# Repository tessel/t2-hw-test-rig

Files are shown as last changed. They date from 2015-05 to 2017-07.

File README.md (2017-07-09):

# t2-hw-test-rig



KiCAD design files for test rigs for Technical Machine's Tessel 2

To download [TM's KiCAD library](https://github.com/technicalmachine/tm-kicad-library), containing all the schematic symbols and footprints, run this command:

```
git submodule update --init
```

## Notes

* We use the daily builds of KiCAD (for [Ubuntu](https://code.launchpad.net/~js-reynaud/+archive/ubuntu/ppa-kicad and [OS X](http://www.kicad-pcb.org/display/KICAD/Installing+KiCad#InstallingKiCad-MacOSX) ) and you should too!
* As a general rule, do not assume that schematic, layout, and manufacturig exports were kept abreast on each commit. Do a fresh export (or use tagged releases) if you intend to actually send off gerbers.

### Troubleshooting

**No components rendered in 3D viewer (OS X):** You may need to change the environment variable for the 3D model path. Run this command and reset KiCad; this fix will work for the duration of your logged in session on the computer:

```
launchctl setenv KISYS3DMOD "/Library/Application Support/kicad/packages3d"
```

## Mechanical Model

Our [physical CAD model](https://cad.onshape.com/documents/50a5c011c1d44d7ca5c90fbf) is available on [OnShape](http://onshape.com), a cloud-based 3D CAD system that is free for public projects. It supports export in a variety of formats to other 3D CAD tools.

## License

CC-BY-SA and/or Solderpad at your option except where otherwise noted.

See `license.txt`.

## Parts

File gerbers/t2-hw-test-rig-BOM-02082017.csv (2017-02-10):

Title | Tessel 2 Test Rig
Revision
Date | Thu 30 Apr 2015
Generated | Monday | May 30 | 2016 'PMt' 12:41:19 PM
Company | Technical Machine | Inc.
Comment 1 | Copyright 2015
Comment 2 | CC-BY-SA and/or Solderpad at your option
Comment 3
Comment 4
Total Parts | 198
Total Unique Parts | 49
Ref | Qty | Value | Footprint
C104 C102 C103 C105 C310 C305 C307 C303 C302 C313 C311 C314 C401 C403 C409 C410 C404 C414 C505 C502 C508 C504 | 22 | 100nF | SMD-0402
C101 C308 C309 C312 | 4 | 10uF | SMD-0402
C201 C207 C202 C405 C411 C412 C406 C415 C503 C506 C509 | 11 | 100pF | SMD-0402
C304 C301 | 2 | 10pF | SMD-0402
C306 | 1 | 1uF | SMD-0402
C501 | 1 | 100nF DNP | SMD-0402
D203 D201 | 2 | PRTR5V0U2X | SMD
D304 | 1 | RED LEDs | LED-0603
D302 | 1 | YELLOW LEDs | LED-0603
D303 | 1 | GREENLEDs | LED-0603
D301 | 1 | BLUELEDs | LED-0603
H601 H602 H603 H604 H605 H606 H607 H608 H609 H610 H611 H612 | 12 | M2.5 | MountingHole_2-5mm
J102 | 1 | BARREL_JACK
J101 J103 J202 | 3 | CONN_01X02 | Pin_Header_Straight_1x02
J201 J203 | 2 | MICROUSB-TH
J204 | 1 | USB_A_TH
J301 | 1 | CONN_02x05 | 0.05 CONN_02x05_0.05in
JP101 JP201 | 2 | JUMPER
L301 L401 L502 | 3 | 10uHtm-kicad-lib | SMD-0603-R
L501 | 1 | 10uH DNP
MP601 MP602 MP606 MP607 MP610 MP611 MP614 MP615 MP620 MP625 MP630 | 11 | Mounting Hardware - See Schematic, Mechanical Sheet
MP603 | 1 | Mounting Hardware - See Schematic, Mechanical Sheet
MP605 MP609 MP613 MP617 MP622 MP627 MP632 | 7 | Mounting Hardware - See Schematic, Mechanical Sheet
MP633 | 1 | Mounting Hardware - See Schematic, Mechanical Sheet
MP618 MP623 MP628 | 3 | Mounting Hardware - See Schematic, Mechanical Sheet
MP604 MP608 MP612 MP616 MP621 MP626 MP631 MP619 MP624 MP629 | 10 | Mounting Hardware - See Schematic, Mechanical Sheet
P102 P103 | 2 | USB A TO MicroUSB A CABLE
P104 | 1 | ETHERNET CABLE
P101 | 1 | 5VDC POWER
P105 P106 | 2 | USB THUMB DRIVE
Q101 | 1 | pMOS | SOT-23
Q403 Q401 Q402 Q404 | 4 | NTR4503NT1G | SOT-23
Q405 Q406 | 2 | CJ2302 DNP | SOT-23
R201 R202 R206 R203 | 4 | 100k | SMD-0402-R
R308 R309 R304 R301 | 4 | 1k | SMD-0402-R
R306 R307 R305 R310 R405 R401 R402 R406 R501 R502 | 10 | 10k | SMD-0402-R
R302 | 1 | 330 | SMD-0402-R
R303 | 1 | 120 | SMD-0402-R
R407 R403 R404 R408 R409 | 5 | 20m | SMD-0805-R
RN502 RN503 RN501 RN504 | 4 | ACASA100221002P100 | SMT | http://www.digikey.com/product-detail/en/vishay-beyschlag/ACASA100221002P100/ACASA-10K-10K-2CT-ND/1869887
SW301 SW302 | 2 | Switch_DPST
TP321 TP302 TP303 TP305 TP306 TP307 TP308 TP309 TP310 TP311 TP312 TP313 TP317 TP318 TP315 TP316 TP314 TP301 TP304 TP324 TP319 TP325 TP326 TP327 TP328 TP401 TP403 TP404 TP402 TP507 TP505 TP503 TP504 TP509 | 34 | 0932-0-15-20-77-14-11-0
U101 | 1 | MAX6102 | SOT-23
U102 | 1 | XC6206P332MR-G | SOT-23
U301 | 1 | ATSAMD21J18A-MUT
U302 U303 | 2 | AAT4610 | SOT-23
U403 U401 U402 U404 U405 | 5 | MAX9919FASA | SOIC-8
U502 U501 U503 | 3 | TSV324IDT | SOIC-14
X301 | 1 | FC-135 | SMT | http://www.seeedstudio.com/wiki/images/7/78/306010055.pdf
BOM made with KICAD_BOM_WIZARD (https://github.com/HashDefineElectronics/KiCad_BOM_Wizard.git)
Generated Monday | May 30 | 2016 'PMt' 12:41:19 PM

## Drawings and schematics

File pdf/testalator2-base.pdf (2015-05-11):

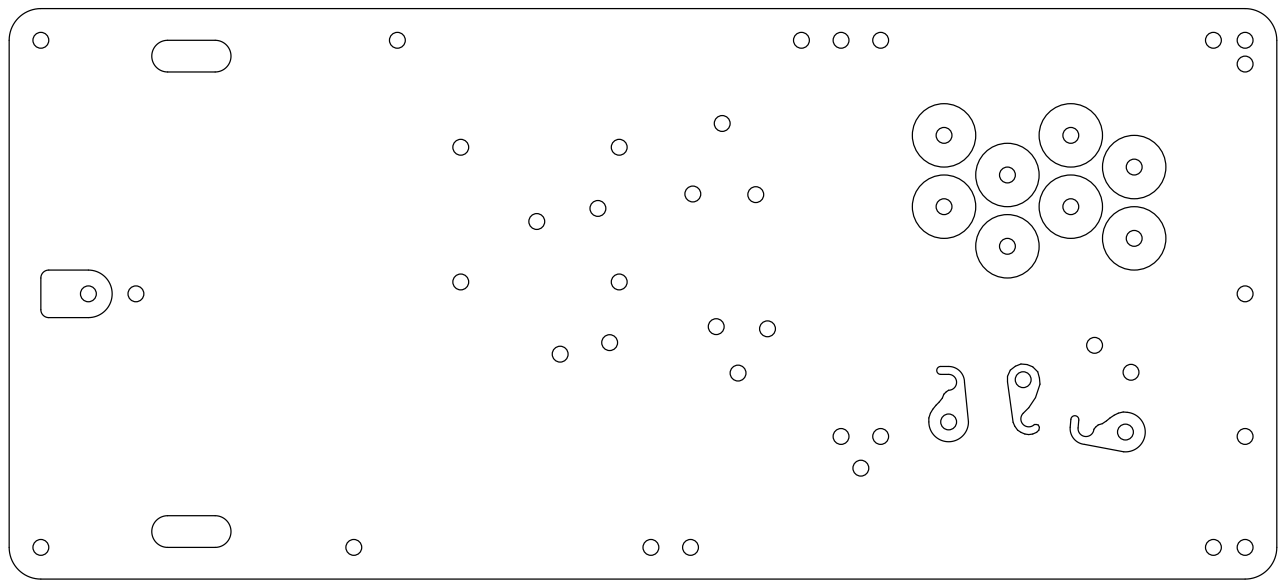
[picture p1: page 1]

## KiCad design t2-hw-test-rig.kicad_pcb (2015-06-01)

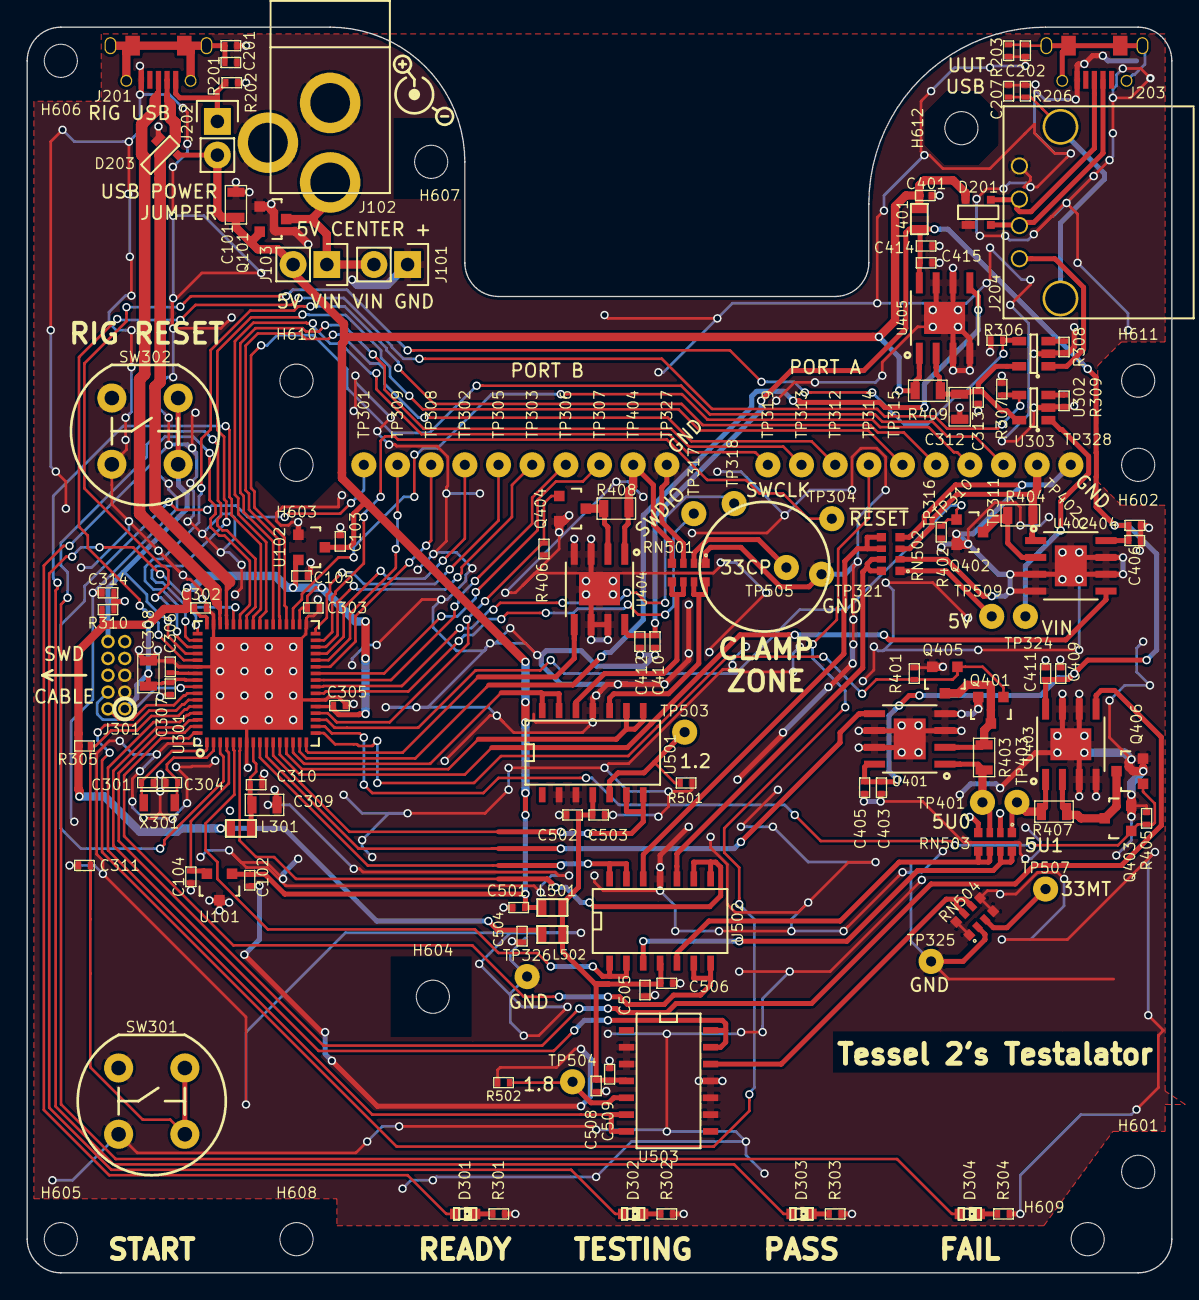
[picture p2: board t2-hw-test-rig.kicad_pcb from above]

Board: 2 copper layers, 86.4 x 94.0 mm, 157 parts (0 on the bottom side), 95 nets.

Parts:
C101, C308, C309, C312: 10uF; SMD-0805-C
C102, C103, C104, C105, C302, C303, C305, C307, C310, C311, C313, C314, C401, C403, C404, C409, C410, C414, C502, C504, C505, C508: 100nF; SMD-0402-C
C201, C202, C207, C405, C406, C411, C412, C415, C503, C506, C509: 100pF; SMD-0402-C
C301, C304: 10pF; SMD-0402-C
C306: 1uF; SMD-0402-C
C501: 100nF DNP; SMD-0402-C
D201, D203: PRTR5V0U2X,215
D301: BLUE; LED-0603
D302: YELLOW; LED-0603
D303: GREEN; LED-0603
D304: RED; LED-0603
H601, H602, H603, H604, H605, H606, H607, H608, H609, H610, H611, H612: M2.5; MountingHole_2-5mm
J101, J103, J202: CONN_01X02; Pin_Header_Straight_1x02
J102: BARREL_JACK
J201, J203: MICROUSB-TH; Seeed-USB-Micro-320010028
J204: USB_A_TH; USB-A
J301: CONN_02x05, 0.05"; CONN_02x05_0.05in
L301, L401, L502: 10uH; SMD-0603-R
L501: 10uH DNP; SMD-0603-R
Q101: pMOS; SOT-23
Q401, Q402, Q403, Q404: CJ2302; SOT-23
Q405, Q406: CJ2302 DNP; SOT-23
R201, R202, R203, R206: 100kR; SMD-0402-R
R301, R304, R308, R309: 1kR; SMD-0402-R
R302: 330R; SMD-0402-R
R303: 120R; SMD-0402-R
R305, R306, R307, R310, R401, R402, R405, R406, R501, R502: 10kR; SMD-0402-R
R403, R404, R407, R408, R409: 20mR 1%; SMD-0805-R
RN501, RN502, RN503, RN504: ACASA100221002P100; ACAS0612
SW301, SW302: Switch_DPST; SPST-TH
TP301, TP302, TP303, TP304, TP305, TP306, TP307, TP308, TP309, TP310, TP311, TP312, TP313, TP314, TP315, TP316, TP317, TP318, TP319, TP321, TP324, TP325, TP326, TP327, TP328, TP401, TP402, TP403, TP404, TP503, TP504, TP505, TP507, TP509: 0932-0-15-20-77-14-11-0
U101: MAX6102; SOT-23
U102: XC6206P332MR-G; SOT-23
U301: ATSAMD21J18A-MUT; QFN-64-1EP_9x9x0.5-8MILDRC
U302, U303: AAT4610; SOT-23-5
U401, U402, U403, U404, U405: MAX9919FASA+; SOIC-8-N-1EP
U501, U502, U503: TSV324IDT; SOIC-14_N
X301: FC-135

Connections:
5VUSB0_DIV_BUFF: U301.64, U502.6, U502.7
5VUSB1_DIV_BUFF: U301.5, U502.1, U502.2
5V_DIV_BUFF: U301.6, U502.8, U502.9
12_BUFF: U301.11, U501.6, U501.7
18_BUFF: U301.61, U503.6, U503.7
33CP_DIV_BUFF: U301.13, U501.8, U501.9
33MT_DIV_BUFF: U301.62, U503.13, U503.14
33PA_DIV_BUFF: U301.9, U502.13, U502.14
33PB_DIV_BUFF: U301.14, U501.13, U501.14
+3V3: C105.1, C302.1, C303.1, C305.1, C307.1, C308.1, C504.1, J301.1, L301.1, L502.2, R305.2, R310.2, U102.2, U301.21, U301.34, U301.48, U301.56
+5V: C101.1, C102.1, C103.1, C401.1, C501.1, D201.4, D203.4, J103.2, J202.2, L401.2, L501.2, Q101.2, R409.1, U101.1, U102.3, U405.1
/CURRENT/5VUSB0_RS-: Q401.3, Q405.3, R403.2, U401.2
/CURRENT/5VUSB1_RS-: Q403.3, Q406.3, R407.2, U403.2
/CURRENT/33PA_RS-: Q402.3, R404.2, U402.2
/CURRENT/33PB_RS-: Q404.3, R408.2, U404.2
/CURRENT/VCC_CSA: C403.1, C404.1, C405.1, C406.1, C409.1, C410.1, C411.1, C412.1, C414.1, C415.1, L401.1, U401.8, U402.8, U403.8, U404.8, U405.8
/OP AMPS/5VUSB0_DIV: RN503.5, RN503.6, U502.5
/OP AMPS/5VUSB1_DIV: RN503.7, RN503.8, U502.3
/OP AMPS/5V_DIV: RN502.7, RN502.8, U502.10
/OP AMPS/33CP_DIV: RN501.7, RN501.8, U501.10
/OP AMPS/33MT_DIV: RN504.6, RN504.7, U503.12
/OP AMPS/33PA_DIV: RN502.5, RN502.6, U502.12
/OP AMPS/33PB_DIV: RN501.5, RN501.6, U501.12
/OP AMPS/UUT_12: R501.1, TP503.~, U501.5
/OP AMPS/UUT_18: R502.1, TP504.~, U503.5
/OP AMPS/VDD_OPAMPS: C502.1, C503.1, C505.1, C506.1, C508.1, C509.1, L501.1, L502.1, U501.4, U502.4, U503.4
/SAM/FAIL_LED: D304.2, U301.42
/SAM/FAIL_MID: D304.1, R304.2
/SAM/PASS_LED: D303.2, U301.41
/SAM/PASS_MID: D303.1, R303.2
/SAM/PORT_A_G1/TX: TP312.~, U301.37
/SAM/PORT_A_G2/RX: TP313.~, U301.38
/SAM/PORT_A_G3: TP319.~, U301.40
/SAM/PORT_A_MISO: TP315.~, U301.49
/SAM/PORT_A_MOSI: TP314.~, U301.59
/SAM/PORT_A_SCK: TP316.~, U301.50
/SAM/PORT_A_SCL: TP311.~, U301.36
/SAM/PORT_A_SDA: TP310.~, U301.35
/SAM/PORT_B_G1/TX: TP308.~, U301.27
/SAM/PORT_B_G2/RX: TP309.~, U301.28
/SAM/PORT_B_G3: TP301.~, U301.3
/SAM/PORT_B_MISO: TP305.~, U301.32
/SAM/PORT_B_MOSI: TP302.~, U301.29
/SAM/PORT_B_SCK: TP303.~, U301.30
/SAM/PORT_B_SCL: TP307.~, U301.26
/SAM/PORT_B_SDA: TP306.~, U301.25
/SAM/READY_LED: D301.2, U301.43
/SAM/READY_MID: D301.1, R301.2
/SAM/SAM_XTAL32_1: C301.1, U301.1, X301.1
/SAM/SAM_XTAL32_2: C304.1, U301.2, X301.2
/SAM/TEST_IN_PROGRESS_LED: D302.2, U301.44
/SAM/TEST_START_BUTTON: C311.1, R305.1, SW301.2, SW301.4, U301.60
/SAM/TIP_MID: D302.1, R302.2
/SAM/UUT_SWCLK: TP318.~, U301.24
/SAM/UUT_SWDIO: TP317.~, U301.23
/SAM/UUT_VIN: TP324.~, U303.1
/SAM/UUT_~ENABLE~_USB: R306.2, U301.51, U302.4
/SAM/UUT_~ENABLE~_VIN: R307.2, U301.53, U303.4
/SAM/UUT_~RESET: TP304.~, U301.31
/SAM/VDDCORE: C306.1, U301.55
/USB/SAM_USB_SHELL: C201.1, J201.6, J201.7, J201.8, J201.9, J201.10, J201.11, R201.1
/USB/UUT_USB_D+: D201.3, J203.3, J204.3
/USB/UUT_USB_D-: D201.2, J203.2, J204.2
/USB/UUT_USB_PASSTHROUGH_SHELL: C202.1, J203.6, J203.7, J203.8, J203.9, J203.10, J203.11, R203.1
/USB/UUT_USB_SHELL: C207.1, J204.5, J204.6, R206.1
/USB/V_USB_IN: J201.1, J202.1, R202.1
/V_IN: J101.2, J102.1, J103.1, Q101.3
CP_VDDANA: C309.1, C310.1, L301.2, U301.8
GND: C101.2, C102.2, C103.2, C104.2, C105.2, C201.2, C202.2, C207.2, C301.2, C302.2, C303.2, C304.2, C305.2, C306.2, C307.2, C308.2, C309.2, C310.2, C311.2, C312.2, C313.2, C314.2, C401.2, C403.2, C404.2, C405.2, C406.2, C409.2, C410.2, C411.2, C412.2, C414.2, C415.2, C501.2, C502.2, C503.2, C504.2, C505.2, C506.2, C508.2, C509.2, D201.1, D203.1, J101.1, J102.2, J102.3, J201.5, J203.5, J204.4, J301.3, J301.5, Q101.1, Q401.2, Q402.2, Q403.2, Q404.2, Q405.2, Q406.2, R201.2, R202.2, R203.2, R206.2, R301.1, R302.1, R303.1, R304.1, R306.1, R307.1, R308.1, R309.1, R401.2, R402.2, R405.2, R406.2, R501.2, R502.2, RN501.1, RN501.3, RN502.2, RN502.4, RN503.2, RN503.4, RN504.1, RN504.2, RN504.4, RN504.5, RN504.8, SW301.1, SW301.3, SW302.1, SW302.3, TP321.~, TP325.~, TP326.~, TP327.~, TP328.~, U101.3, U102.1, U301.7, U301.22, U301.33, U301.47, U301.54, U301.65, U302.2, U303.2, U401.3, U401.4, U401.6, U401.7, U401.9, U402.3, U402.4, U402.6, U402.7, U402.9, U403.3, U403.4, U403.6, U403.7, U403.9, U404.3, U404.4, U404.6, U404.7, U404.9, U405.3, U405.4, U405.6, U405.7, U405.9, U501.2, U501.3, U501.11, U502.11, U503.2, U503.3, U503.9, U503.10, U503.11
I_PA33: U301.12, U402.5
I_PB33: U301.16, U404.5
I_USB0: U301.10, U401.5
I_USB1: U301.63, U403.5
I_UUT: U301.15, U405.5
unnamed: R308.2, U302.3
unnamed: R309.2, U303.3
PA33_SHORT: Q402.1, R402.1, U301.19
PB33_SHORT: Q404.1, R406.1, U301.20
SAM_USB_D+: D203.2, J201.3, U301.46
SAM_USB_D-: D203.3, J201.2, U301.45
SAM_~RESET: C314.1, J301.10, R310.1, SW302.2, SW302.4, U301.52
SWCLK: J301.4, U301.57
SWDIO: J301.2, U301.58
USB0_SHORT: Q401.1, Q405.1, R401.1, U301.17
USB1_SHORT: Q403.1, Q406.1, R405.1, U301.18
UUT_5V: RN502.1, TP509.~
UUT_5VUSB0: R403.1, RN503.3, TP401.~, U401.1
UUT_5VUSB1: R407.1, RN503.1, TP403.~, U403.1
UUT_5V_UPSTREAM: C312.1, C313.1, R409.2, U302.5, U303.5, U405.2
UUT_33CP: RN501.2, TP505.~
UUT_33MT: RN504.3, TP507.~
UUT_33PA: R404.1, RN502.3, TP402.~, U402.1
UUT_33PB: R408.1, RN501.4, TP404.~, U404.1
UUT_VINUSB: J204.1, U302.1
V_REF: C104.1, U101.2, U301.4

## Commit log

2015-04-17 added fp-lib-table to reference tm-kicad-lib
2015-04-17 added gitignore, tm-kicad-lib as submodule
2015-04-17 created project, schematic
    [t2-hw-test-rig.sch]
2015-04-17 added the SAM and some power-related things
    [t2-hw-test-rig.sch]
2015-04-17 put at least one of most of the critical components onto the schematic
    [t2-hw-test-rig.sch]
2015-04-17 added current sense amplifier
    [t2-hw-test-rig.sch]
2015-04-17 CSA support circuitry
    [t2-hw-test-rig.sch]
2015-04-17 swapped switcher for an ldo
    [t2-hw-test-rig.sch]
2015-04-17 picked an nmos
    [t2-hw-test-rig.sch]
2015-04-22 broke out usb and sam to sheets
    [t2-hw-test-rig.sch]
2015-04-22 added individual sheets for sam, usb, current sense
    [SAM.sch, USB.sch, current.sch]
2015-04-23 ...and now the schematics are in git
    [SAM.sch, current.sch, t2-hw-test-rig.sch]
2015-04-23 sercoms in place
    [SAM.sch]
2015-04-24 pin allocations and finally got the opamp in there
    [SAM.sch, current.sch, t2-hw-test-rig.sch]
2015-04-24 resistor network
    [current.sch]
2015-04-28 resistor network = RN
    [current.sch]
2015-04-28 connected analog things, lots of testpoints
    [SAM.sch, USB.sch, current.sch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]
2015-04-29 moved a bunch of things around inside the schematics
    [SAM.sch, USB.sch]
2015-04-30 schematic check with kevin. misc fixes, mostly on usb
    [SAM.sch, USB.sch, current.sch]
2015-05-01 passed schematic review
    [SAM.sch, USB.sch, current.sch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]
2015-05-01 sheet info filled in on all sheets
    [SAM.sch, USB.sch, current.sch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]
2015-05-01 added testpoint part number, small net naming changes
    [SAM.sch, USB.sch, current.sch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]
2015-05-01 annotated, netlist
    [SAM.sch, USB.sch, current.sch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]
2015-05-04 swapped out new USB_A_TH symbol
    [SAM.sch, USB.sch, current.sch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]
2015-05-04 unconventional library hack:moved tm lib above all others so parts come from there first
    [SAM.sch, USB.sch, current.sch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]
2015-05-04 components and footprints
    [SAM.sch, USB.sch, current.sch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]
2015-05-04 swapped testpoints
    [SAM.sch, current.sch, opamps.sch]
2015-05-04 started pcb file with t2 drills
    [t2-hw-test-rig.kicad_pcb]
2015-05-04 added t2-hw-test-rig.kicad_pcb-bak to gitignore
2015-05-05 on to layout! and what an adventure it will be...
    [SAM.sch, current.sch, opamps.sch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]
2015-05-06 significant progress on placement, sch changes for adc routing
    [SAM.sch, current.sch, opamps.sch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]
2015-05-06 usb refactor on sch and pcb, mechanical constraints on bcp
    [SAM.sch, USB.sch, current.sch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]
2015-05-06 packed parts in
    [t2-hw-test-rig.kicad_pcb]
2015-05-06 moved mechanicals to a separate sheet
    [SAM.sch, USB.sch, current.sch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]
2015-05-06 consolidated csa power, removed drill map text
    [current.sch, opamps.sch, t2-hw-test-rig.kicad_pcb]
2015-05-06 placement "complete"
    [t2-hw-test-rig.kicad_pcb]
2015-05-06 drc tweaks
    [t2-hw-test-rig.kicad_pcb]
2015-05-07 mostly routed... time to go back and pin mux
    [current.sch, opamps.sch, t2-hw-test-rig.kicad_pcb]
2015-05-07 more analog pinswaps
    [SAM.sch, t2-hw-test-rig.kicad_pcb]
2015-05-07 analog routed!
    [t2-hw-test-rig.kicad_pcb]
2015-05-07 now with fewer traces through mounting holes...
    [t2-hw-test-rig.kicad_pcb]
2015-05-07 time to move on to the digital side
    [t2-hw-test-rig.kicad_pcb]
2015-05-07 port b
    [t2-hw-test-rig.kicad_pcb]
2015-05-07 passes drc except for qfn footprint...
    [SAM.sch, mechanical.sch, t2-hw-test-rig.kicad_pcb]
2015-05-07 ready to swap the qfn
    [t2-hw-test-rig.kicad_pcb]
2015-05-07 qfn swapped, another mount hole added, passes drc
    [SAM.sch, mechanical.sch, t2-hw-test-rig.kicad_pcb]
2015-05-08 moved usb testpoints
    [t2-hw-test-rig.kicad_pcb]
2015-05-08 usb port and barrel jack tweaks
    [USB.sch, t2-hw-test-rig.kicad_pcb]
2015-05-08 still easier access to usb
    [USB.sch, mechanical.sch, t2-hw-test-rig.kicad_pcb]
2015-05-11 soic-8-1ep footprint fix, moved mount holes for mech clearance
    [t2-hw-test-rig.kicad_pcb]
2015-05-11 saved and closed. gerber export
    [t2-hw-test-rig-B_Cu.gbr, t2-hw-test-rig-B_Mask.gbr, t2-hw-test-rig-B_Paste.gbr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]
2015-05-11 added idf models for moving to ME CAD
2015-05-11 one more potential mechanical issue removed
    [t2-hw-test-rig-B_Cu.gbr, t2-hw-test-rig-B_Mask.gbr, t2-hw-test-rig-B_Paste.gbr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]
2015-05-11 added test rig base plat outline in bfab
    [t2-hw-test-rig.kicad_pcb]
2015-05-11 adds base plate laser cut template
2015-05-22 opamp rotation
    [opamps.sch, t2-hw-test-rig.kicad_pcb]
2015-06-01 pulldowns on 1.2, 1.8 and power swap for opamps
    [opamps.sch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]
2017-02-05 here you go kelsey. the bom should have been added here long ago...
    [t2-hw-test-rig.csv]
2017-02-10 updates to latest BOM (Seeed made some part swaps)
    [t2-hw-test-rig-BOM-02082017.csv, t2-hw-test-rig.csv]
